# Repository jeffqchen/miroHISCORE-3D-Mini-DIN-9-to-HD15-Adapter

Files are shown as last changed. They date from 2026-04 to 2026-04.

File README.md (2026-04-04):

# miroHISCORE 3D Mini DIN 9 to HD15 Adapter



The miroHISCORE 3D line of 3Dfx Voodoo 1 & 2 cards use a proprietary Mini DIN 9 pin connector to route the output signal of the 2D video card to the Voodoo card. This cable is often missing after many decades. Therefore, I've created this adapter board to convert the DIN connector to a standard male VGA port, so an ordinary Voodoo passthrough cable can be used.

Note: This adapter is also compatible with the Canopus Pure3d line of Voodoo cards.

## Parts

Main:

- PCB - [Gerber File](https://github.com/jeffqchen/miroHISCORE-3D-Mini-DIN-9-to-HD15-Adapter/blob/main/KiCAD/jlcpcb/production_files/GERBER-miroHISCORE%20Adapter.zip)
- 9 pin Mini DIN Female Recepticle, Through Hole - [Link](https://github.com/jeffqchen/JeffParts/blob/main/Connectors/Mini%20DIN/Female/9%20Pin/info.md)
- VGA Port Full Depth, Male, Right Angle, Through Hole - [Link](https://github.com/jeffqchen/JeffParts/blob/main/Connectors/HD15/Full/Male/info.md)

Accessories:

- Mini DIN 9 Pin Cable, Male Pin, Straight - [Link](https://github.com/jeffqchen/JeffParts/blob/main/Cable/Mini%20DIN/9%20Pin/%20Male/Straight/info.md)
  - Buy one as short as possible. Mine is 1 meter.
- VGA bracket - With the VGA port opening near the middle.
  - (Optional) 3D Printed bracke - [Link](https://github.com/jeffqchen/miroHISCORE-3D-Mini-DIN-9-to-HD15-Adapter/blob/main/3D%20Print/miroHISCORE%203D%20Daughter%20Board%20Bracket.stl)

## Assembly

### PCB Assembly

Populate the PCB with the two ports.

 

### VGA Bracket

Drill 29mm from center of VGA port, a hole of 11-12 mm diameter.



*(The hole in my photo is obviously off)*

#### 3D Printed Bracket

The 3D printed bracket needs to be bent towards the groove with hot air to become usable. 

### Final Assembly

Undo the hex nuts from the VGA port with a 3/16 socket, insert the VGA port through the back of the bracket, and tighten the nuts back on.

## Usage

Connect the daughter board and the miroHISCORE 3D card with the 9 pin Mini DIN cable.



Connect the 2D VGA card to the daughter card with a Voodoo passthrough card.

Connect the VGA output of the miroHISCORE 3D card to the display.

## Technical Details

I found this pin definition on The Retro Web, which turned out to be correct.



## Special Thanks

The Retro Web - [Link](https://theretroweb.com/expansioncards/s/miro-mirohiscore-2-3d)

--------

Shield: [][cc-by-sa]

This work is licensed under a
[Creative Commons Attribution-ShareAlike 4.0 International License][cc-by-sa].

[][cc-by-sa]

[cc-by-sa]: http://creativecommons.org/licenses/by-sa/4.0/
[cc-by-sa-image]: https://licensebuttons.net/l/by-sa/4.0/88x31.png
[cc-by-sa-shield]: https://img.shields.io/badge/License-CC%20BY--SA%204.0-lightgrey.svg

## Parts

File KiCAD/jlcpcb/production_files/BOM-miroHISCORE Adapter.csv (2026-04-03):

Comment | Designator | Footprint | LCSC | Quantity
M3 Screw Hole | REF** | M3 Screw Hole |  | 1
VGA | P1 | DSUB-15-HD_Pins_Horizontal_P2.29x2.54mm_EdgePinOffset8.35mm_Housed_MountingHolesOffset10.89mm |  | 1
Mini-DIN-9 | J1 | 9DIN Female |  | 1

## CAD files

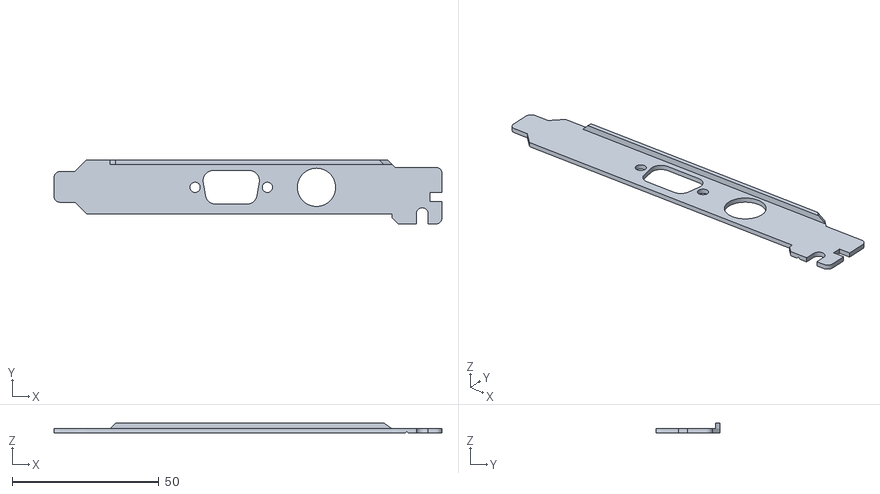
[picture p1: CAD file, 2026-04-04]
3D Print/miroHISCORE 3D Daughter Board Bracket.stl
132.0 x 21.7 x 3.50

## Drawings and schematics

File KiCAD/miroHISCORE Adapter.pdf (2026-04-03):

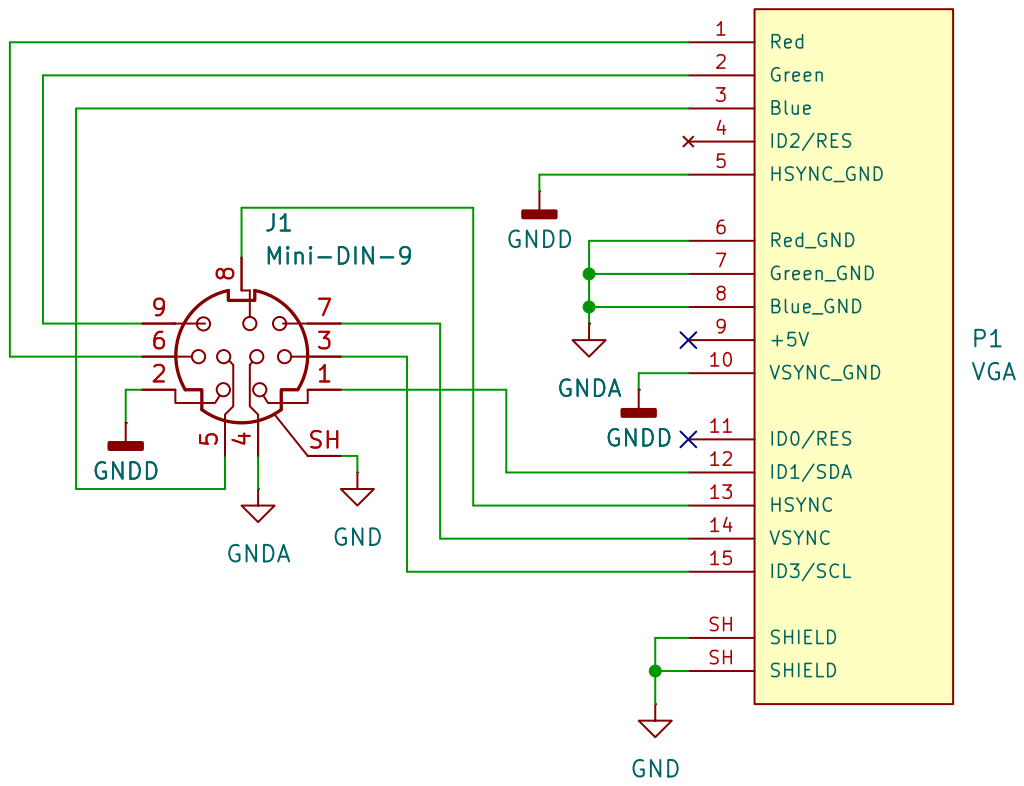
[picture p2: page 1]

Jeff Chen
Sheet: /
D Date: 2026-04-03 KiCad E.D.A. 10.0.0
File: miroHISCORE Adapter.kicad_sch
Title: miroHISCORE 3D Mini DIN 9 Pin to HD15 Adapter

Size: A4 | Rev: 1.0

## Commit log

2026-04-03 Initial Upload
    [BOM-miroHISCORE Adapter.csv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]
2026-04-03 Enhance README with adapter details and assembly steps
    Expanded the README with detailed information about the adapter, including parts and assembly instructions.
2026-04-03 Update 9din footprint
    [CPL-miroHISCORE Adapter.csv, miroHISCORE Adapter-B_Cu.gbr, miroHISCORE Adapter-B_Mask.gbr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]
2026-04-04 Add parts and accessory links to README
    Updated the README to include links for parts and accessories related to the adapter board.
2026-04-04 Revise README with assembly and usage details
    Updated assembly instructions and added usage section.
2026-04-04 Clarify Mini DIN 9 Pin Cable description
    Updated the description for Mini DIN 9 Pin Cable to include a recommendation for length.
2026-04-04 Add 3D printable bracket
    [miroHISCORE 3D Daughter Board Bracket.stl]
2026-04-04 Add optional 3D printed bracket information
    Added optional 3D printed bracket link to the README.
2026-04-04 Add 3D printed bracket instructions to README
    Added instructions for bending the 3D printed bracket.
2026-04-04 Update VGA bracket hole diameter specification

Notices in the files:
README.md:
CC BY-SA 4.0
